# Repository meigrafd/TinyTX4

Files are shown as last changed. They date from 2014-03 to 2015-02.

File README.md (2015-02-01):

TinyTX4
=======

RFM12B based TinyTX Transmitter

Projekt Page: http://www.forum-raspberrypi.de/Thread-messen-steuern-regeln-batteriebetriebene-funk-sensoren

## Compiled Sketch size

#### with RFM12B lib:

Send_DHT22.ino --> 5.254 Bytes.  
Send_DHT22.ino & encrypt --> 6.896 Bytes.  
Send_DHT22_Watchdog.ino --> 5.512 Bytes.  
Send_DHT22_Watchdog.ino & encrypt --> 7.154 Bytes.  

Send_DS18B20.ino --> 7.342 Bytes.  
Send_DS18B20.ino & encrypt --> ... 768 bytes to big.  
Send_DS18B20_Watchdog.ino --> 7.590 Bytes.  
Send_DS18B20_Watchdog.ino & encrypt --> ... 1012 bytes to big.  

Send_ReedSwitch_Watchdog.ino --> 4.312 Bytes.  
Send_ReedSwitch_Watchdog.ino & encrypt --> 5.954 Bytes.  

#### with JeeLib:

Send_DHT22_Watchdog_JeeLib.ino --> 5.082 Bytes.  
Send_DHT22_Watchdog_JeeLib.ino & encrypt --> 6.746 Bytes.  

Send_DS18B20_Watchdog_JeeLib.ino --> 7.160 Bytes.  
Send_DS18B20_Watchdog_JeeLib.ino & encrypt --> ... 578 bytes to big.  

Send_ReedSwitch_Watchdog_JeeLib.ino --> 3.870 Bytes.  
Send_ReedSwitch_Watchdog_JeeLib.ino & encrypt --> 5.534 Bytes.  

Send_BMP085_Watchdog_JeeLib.ino --> 6.266 Bytes.  
Send_BMP085_Watchdog_JeeLib.ino & encrypt --> 7.894 Bytes.

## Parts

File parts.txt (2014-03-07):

Partlist

Exported from tinytx3.brd at 17.02.2014 13:12:31

EAGLE Version 6.4.0 Copyright (c) 1988-2013 CadSoft

Assembly variant: 

Part         Value          Package  Library        Position (mm)         Orientation

ANT                         1,6/0,8  wirepad        (20.86 6.25)          R0
BATANSCHLUSS                1X02     pinhead        (15.24 2.54)          R0
C1           100n           C0805    rcl            (27.48 6.35)          R180
C2           100n           C0805    rcl            (14.45 27.07)         MR90
C3                          C0805    rcl            (27.94 11.43)         R0
C4                          C0805    rcl            (31.75 8.89)          R0
IC1          ATTINY84       SOIC14   avr-5          (7.82 25.8)           MR0
JP1          No Booster     1X02     pinhead        (22.86 2.54)          R180
JP2                         1X03     pinhead        (39.37 34.29)         R0
JP3                         1X03     pinhead        (39.37 30.48)         R0
JP4                         1X03     pinhead        (39.37 26.67)         R0
JP5                         1X03     pinhead        (39.37 22.86)         R0
JP6                         1X03     pinhead        (39.37 19.05)         R0
JP7                         1X03     pinhead        (39.37 15.24)         R0
JP8                         1X03     pinhead        (39.37 11.43)         R0
JP9                         1X03     pinhead        (39.37 7.62)          R0
JP10                        1X02     pinhead        (40.64 3.81)          R0
L1           L1616FPS       L1616    L1616FSR       (29.21 17.78)         R0
PAD1                        1,6/0,9  wirepad        (13.97 36.83)         R0
PAD2                        1,6/0,9  wirepad        (16.51 36.83)         R0
PAD3                        1,6/0,9  wirepad        (19.05 36.83)         R0
PAD4                        1,6/0,9  wirepad        (21.59 36.83)         R0
PAD5                        1,6/0,9  wirepad        (24.13 36.83)         R0
PAD6                        1,6/0,9  wirepad        (26.67 36.83)         R0
PAD7                        1,6/0,9  wirepad        (29.21 36.83)         R0
PAD8                        1,6/0,9  wirepad        (31.75 36.83)         R0
PAD9                        1,6/0,9  wirepad        (13.97 34.29)         R0
PAD10                       1,6/0,9  wirepad        (16.51 34.29)         R0
PAD11                       1,6/0,9  wirepad        (19.05 34.29)         R0
PAD12                       1,6/0,9  wirepad        (21.59 34.29)         R0
PAD13                       1,6/0,9  wirepad        (24.13 34.29)         R0
PAD14                       1,6/0,9  wirepad        (26.67 34.29)         R0
PAD15                       1,6/0,9  wirepad        (29.21 34.29)         R0
PAD16                       1,6/0,9  wirepad        (31.75 34.29)         R0
R1           10k            R0805    rcl            (30.48 21.59)         MR270
SV1                         1X08     pinhead        (22.86 39.37)         R0
SV2                         ML6      con-harting-ml (25.4 25.4)           R0
U$1          RFM12B         RFM12B   JeeParts       (11.43 13.87)         R0
U$2          LTC3525        TSOT23-6 ltc3525        (29.21 13.97)         R270

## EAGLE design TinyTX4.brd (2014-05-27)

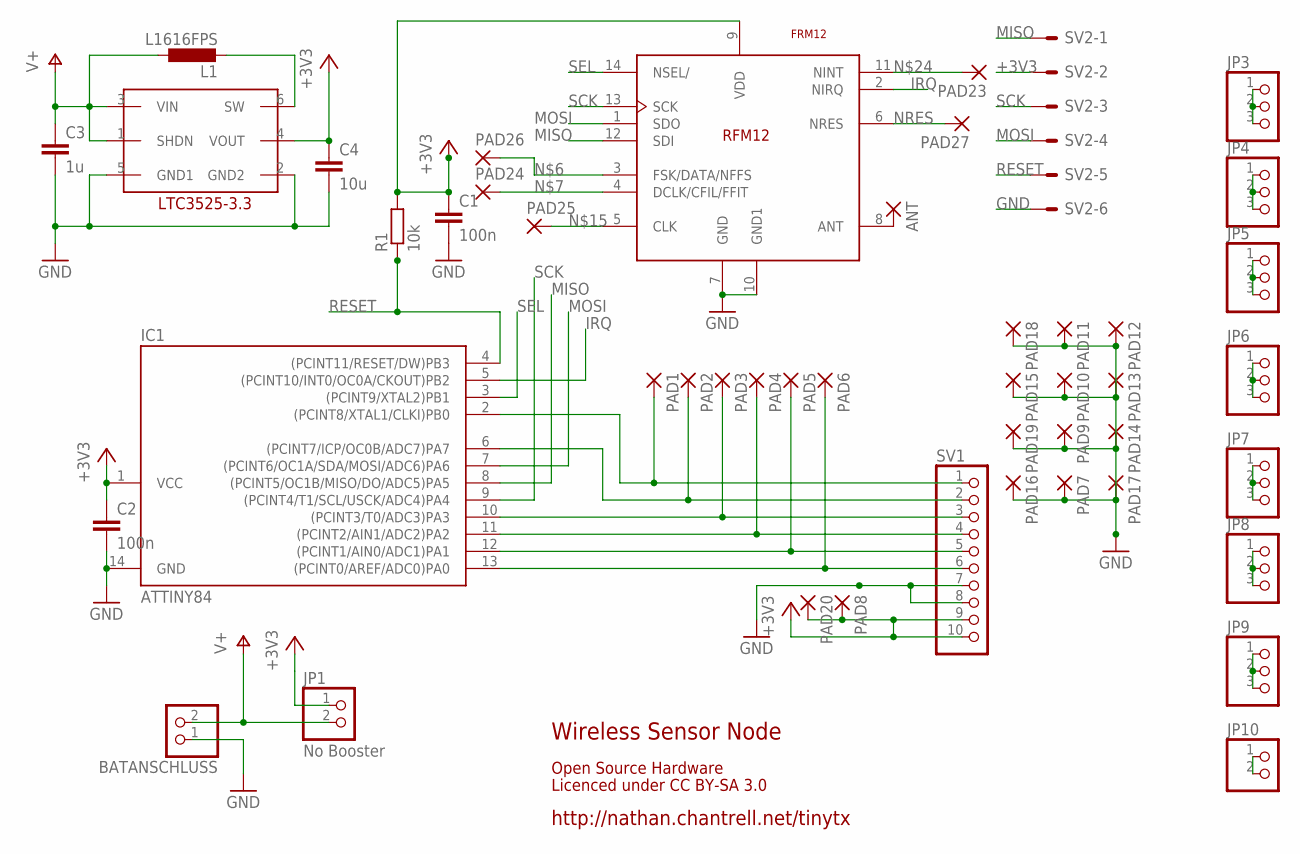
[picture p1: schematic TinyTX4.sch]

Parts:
ANT: 1,6/0,8
BATANSCHLUSS: PINHD-1X2; 1X02
C1, C2: 100n; C0805
C3: 1u; C0805
C4: 10u; C0805
IC1: ATTINY84; SOIC14
IC2: IC2; TSOT23-6
JP1: No Booster; 1X02
JP3, JP4, JP5, JP6, JP7, JP8, JP9: PINHD-1X3; 1X03
JP10: PINHD-1X2; 1X02
L1: L1616FPS; L1616
PAD1, PAD2, PAD3, PAD4, PAD5, PAD6, PAD7, PAD8, PAD9, PAD10, PAD11, PAD12, PAD13, PAD14, PAD15, PAD16, PAD17, PAD18, PAD19, PAD20, PAD23, PAD24, PAD25, PAD26, PAD27: 1,6/0,9
R1: 10k; R0805
SV1: PINHD-1X10; 1X10
SV2: ML6E; ML6
U$3: FRM12; RFM12

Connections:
+3V3: C1.1, C2.1, C4.1, IC1.1 (VCC), IC2.4 (VOUT), JP1.1, PAD8.1, PAD20.1, R1.2, SV1.9, SV1.10, SV2.2, U$3.9 (VDD)
ANT: ANT.1, U$3.8 (ANT)
GND: BATANSCHLUSS.1, C1.2, C2.2, C3.2, C4.2, IC1.14 (GND), IC2.2 (GND2), IC2.5 (GND1), PAD7.1, PAD9.1, PAD10.1, PAD11.1, PAD12.1, PAD13.1, PAD14.1, PAD15.1, PAD16.1, PAD17.1, PAD18.1, PAD19.1, SV1.7, SV1.8, SV2.6, U$3.7 (GND), U$3.10 (GND1)
IRQ: IC1.5 ((PCINT10/INT0/OC0A/CKOUT)PB2), U$3.2 (NIRQ)
MISO: IC1.8 ((PCINT5/OC1B/MISO/DO/ADC5)PA5), SV2.1, U$3.12 (SDI)
MOSI: IC1.7 ((PCINT6/OC1A/SDA/MOSI/ADC6)PA6), SV2.4, U$3.1 (SDO)
unnamed: PAD26.1, U$3.3 (FSK/DATA/NFFS)
unnamed: PAD24.1, U$3.4 (DCLK/CFIL/FFIT)
unnamed: IC1.6 ((PCINT7/ICP/OC0B/ADC7)PA7), PAD2.1, SV1.2
unnamed: IC1.13 ((PCINT0/AREF/ADC0)PA0), PAD6.1, SV1.6
unnamed: IC1.12 ((PCINT1/AIN0/ADC1)PA1), PAD5.1, SV1.5
unnamed: IC1.2 ((PCINT8/XTAL1/CLKI)PB0), PAD1.1, SV1.1
unnamed: IC2.6 (SW), L1.P$2 (2)
unnamed: IC1.11 ((PCINT2/AIN1/ADC2)PA2), PAD4.1, SV1.4
unnamed: IC1.10 ((PCINT3/T0/ADC3)PA3), PAD3.1, SV1.3
unnamed: PAD25.1, U$3.5 (CLK)
unnamed: JP3.1, JP3.2, JP3.3
unnamed: JP4.1, JP4.2, JP4.3
unnamed: JP5.1, JP5.2, JP5.3
unnamed: JP10.1, JP10.2
unnamed: JP6.1, JP6.2, JP6.3
unnamed: JP9.1, JP9.2, JP9.3
unnamed: JP7.1, JP7.2, JP7.3
unnamed: JP8.1, JP8.2, JP8.3
unnamed: PAD23.1, U$3.11 (NINT)
NRES: PAD27.1, U$3.6 (NRES)
RESET: IC1.4 ((PCINT11/RESET/DW)PB3), R1.1, SV2.5
SCK: IC1.9 ((PCINT4/T1/SCL/USCK/ADC4)PA4), SV2.3, U$3.13 (SCK)
SEL: IC1.3 ((PCINT9/XTAL2)PB1), U$3.14 (NSEL/)
V+: BATANSCHLUSS.2, C3.1, IC2.1 (SHDN), IC2.3 (VIN), JP1.2, L1.P$1 (1)

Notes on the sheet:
http://nathan.chantrell.net/tinytx
Wireless Sensor Node
Licenced under CC BY-SA 3.0
Open Source Hardware

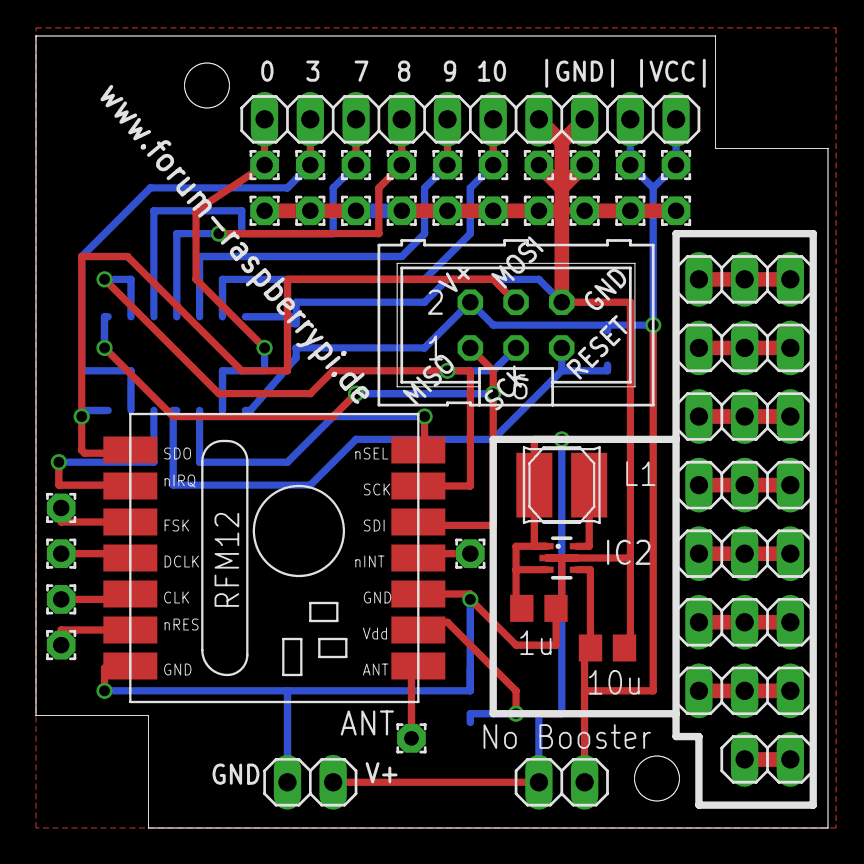
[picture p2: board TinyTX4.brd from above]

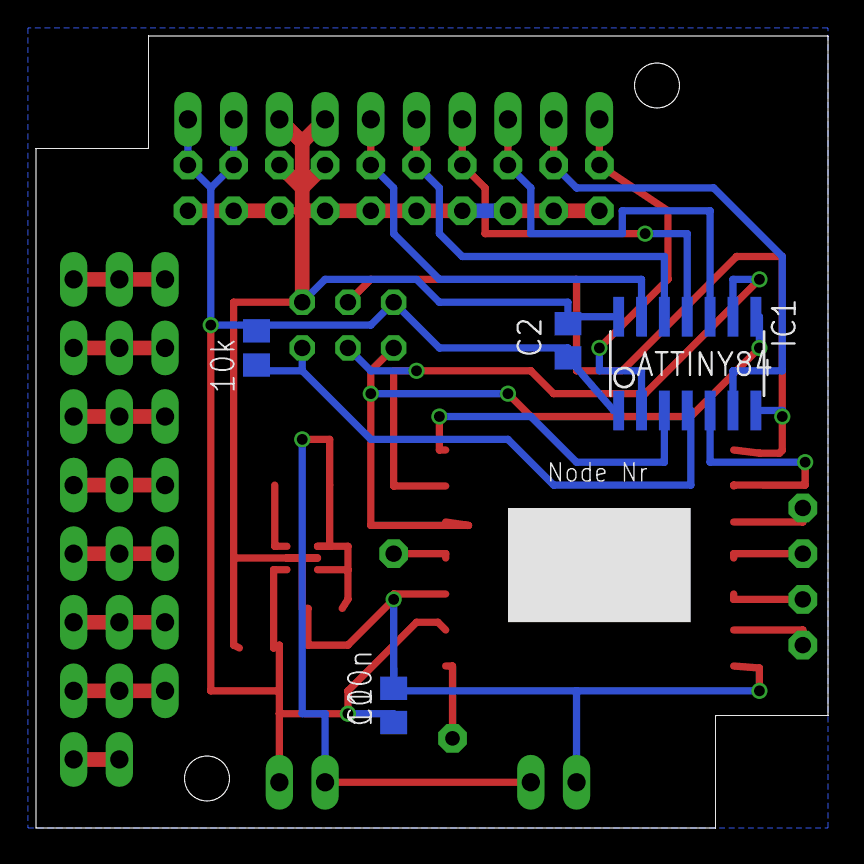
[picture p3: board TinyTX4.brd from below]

Board: 2 copper layers, 44.0 x 44.0 mm, 47 parts (4 on the bottom side), 30 nets.

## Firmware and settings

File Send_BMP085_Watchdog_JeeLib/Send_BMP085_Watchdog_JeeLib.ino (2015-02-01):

//----------------------------------------------------------------------------------------------------------------------
// RFM12B Sender for BMP085 Wireless Air Pressure/Temperature Sensor with Watchdog (saves much more Power!)
//
// Using the BMP085 sensor connected via I2C
// I2C can be connected with SDA to D8 and SCL to D7 or SDA to D10 and SCL to D9
//
//
//  NOTE: SCL and SDA needs pull-up resistors for each I2C bus.
//  2.2kOhm...10kOhm, typ. 4.7kOhm
//----------------------------------------------------------------------------------------------------------------------
// modified by meigrafd @ 01.02.2015
//----------------------------------------------------------------------------------------------------------------------
#include <JeeLib.h> // https://github.com/jcw/jeelib
#include <PortsBMP085.h> // Part of JeeLib
#include <avr/sleep.h>

// Power-Save-Stuff.
// http://www.surprisingedge.com/low-power-atmegatiny-with-watchdog-timer/
// https://www.sparkfun.com/tutorials/309
// http://jeelabs.org/tag/lowpower/
volatile int watchdog_counter;
// Watchdog Interrupt Service / is executed when  watchdog timed out
ISR(WDT_vect) { watchdog_counter++; }

// 0=16ms, 1=32ms, 2=64ms, 3=128ms, 4=250ms, 5=500ms
// 6=1sec, 7=2sec, 8=4sec, 9=8sec
// From: http://interface.khm.de/index.php/lab/experiments/sleep_watchdog_battery/
int watchdog_wakeup = 9;  // Wake up after 8 sec
//------------------------------------------------------------------------------
// You will need to initialize the radio by telling it what ID it has and what network it's on
// The NodeID takes values from 1-127, 0 is reserved for sending broadcast messages (send to all nodes)
// The Network ID takes values from 0-255
// By default the SPI-SS line used is D10 on Atmega328. You can change it by calling .SetCS(pin) where pin can be {8,9,10}
#define NODEID         20   // network ID used for this unit
#define NETWORKID     210   // the network ID we are on
#define GATEWAYID      22   // the node ID we're sending to
#define FREQ   RF12_433MHZ  // Frequency of RFM12B module

#define ACK_TIME     2000   // # of ms to wait for an ack
#define requestACK   false   // request ACK? (true/false)
#define SENDDELAY  300000   // wait this many ms between sending packets. 300000ms / 1000 / 8 = 37,5 * 8sec = 5Min.
//------------------------------------------------------------------------------
// PIN-Konfiguration 
//------------------------------------------------------------------------------
// SENSOR pins
#define BMP085_POWER 9   // BMP085 Power pin is connected on D9
PortI2C i2c (2);         // BMP085 SDA to D8 and SCL to D7
//PortI2C i2c (1);      // BMP085 SDA to D10 and SCL to D9
// LED pin
#define LEDpin 0         // D8, PA2 (ATtiny pin 11) - set to 0 to disable LED
//------------------------------------------------------------------------------
/*
                     +-\/-+
               VCC  1|    |14  GND
          (D0) PB0  2|    |13  AREF (D10)
          (D1) PB1  3|    |12  PA1 (D9)
       (PB3) RESET  4|    |11  PA2 (D8)
INT0  PWM (D2) PB2  5|    |10  PA3 (D7)
      PWM (D3) PA7  6|    |9   PA4 (D6) SCK
SDA   PWM (D4) PA6  7|    |8   PA5 (D5) PWM
                     +----+
*/

//Modes:
// MODE_ULTRA_LOW_POWER    0 //oversampling=0, internalsamples=1, maxconvtimepressure=4.5ms, avgcurrent=3uA, RMSnoise_hPA=0.06, RMSnoise_m=0.5
// MODE_STANDARD           1 //oversampling=1, internalsamples=2, maxconvtimepressure=7.5ms, avgcurrent=5uA, RMSnoise_hPA=0.05, RMSnoise_m=0.4
// MODE_HIGHRES            2 //oversampling=2, internalsamples=4, maxconvtimepressure=13.5ms, avgcurrent=7uA, RMSnoise_hPA=0.04, RMSnoise_m=0.3
// MODE_ULTRA_HIGHRES      3 //oversampling=3, internalsamples=8, maxconvtimepressure=25.5ms, avgcurrent=12uA, RMSnoise_hPA=0.03, RMSnoise_m=0.25
BMP085 psensor (i2c, 3); // ultra high resolution

//encryption is OPTIONAL
//to enable encryption you will need to:
// - provide a 16-byte encryption KEY (same on all nodes that talk encrypted)
// - to call .Encrypt(KEY) to start encrypting
// - to stop encrypting call .Encrypt(NULL)
//#define KEY   "ABCDABCDABCDABCD"

// Temperatur-String zum Versand
char msg[26];

int16_t temp;	// Temperature reading
int32_t pres;	// Pressure reading

// 7,5 * 8sec = 1 Min. 37,5 * 8sec = 5Min.
int watchdog_limit = SENDDELAY / 1000 / 8;

//########################################################################################################################

static void activityLed (byte state, byte time = 0) {
  if (LEDpin) {
    pinMode(LEDpin, OUTPUT);
    if (time == 0) {
      digitalWrite(LEDpin, state);
    } else {
      digitalWrite(LEDpin, state);
      delay(time);
      digitalWrite(LEDpin, !state);
    }
  }
}

// blink led
static void blink (byte pin, byte n = 3) {
  if (LEDpin) {
    pinMode(pin, OUTPUT);
    for (byte i = 0; i < 2 * n; ++i) {
      delay(100);
      digitalWrite(pin, !digitalRead(pin));
    }
  }
}

//--------------------------------------------------------------------------------------------------
// Read current supply voltage
//--------------------------------------------------------------------------------------------------
long readVcc() {
  // Read 1.1V reference against AVcc
  // set the reference to Vcc and the measurement to the internal 1.1V reference
  #if defined(__AVR_ATmega32U4__) || defined(__AVR_ATmega1280__) || defined(__AVR_ATmega2560__)
      ADMUX = _BV(REFS0) | _BV(MUX4) | _BV(MUX3) | _BV(MUX2) | _BV(MUX1);
  #elif defined (__AVR_ATtiny24__) || defined(__AVR_ATtiny44__) || defined(__AVR_ATtiny84__)
      ADMUX = _BV(MUX5) | _BV(MUX0);
  #elif defined (__AVR_ATtiny25__) || defined(__AVR_ATtiny45__) || defined(__AVR_ATtiny85__)
      ADMUX = _BV(MUX3) | _BV(MUX2);
  #else
      ADMUX = _BV(REFS0) | _BV(MUX3) | _BV(MUX2) | _BV(MUX1);
  #endif
  delay(2); // Wait for Vref to settle
  ADCSRA |= _BV(ADSC); // Start conversion
  while (bit_is_set(ADCSRA,ADSC)); // measuring
  uint8_t low  = ADCL; // must read ADCL first - it then locks ADCH
  uint8_t high = ADCH; // unlocks both
  long result = (high<<8) | low;
  //result = 1125300L / result; // Back-Calculate Vcc (in mV); 1125300 = 1.1*1023*1000
  result = 1126400L / result; // Back-calculate Vcc in mV
  return result;
}

//--------------------------------------------------------------------------------------------------
// Power Save Functions
//--------------------------------------------------------------------------------------------------

// Enable / Disable ADC, saves ~230uA
void enableADC(bool b) {
  if (b == true){
    bitClear(PRR, PRADC); // power up the ADC
    ADCSRA |= bit(ADEN);  // enable the ADC
    delay(10);
  } else {
    ADCSRA &= ~ bit(ADEN); // disable the ADC
    bitSet(PRR, PRADC);    // power down the ADC
  }
}

// send ATtiny into Power Save Mode
void goToSleep() {
  // SLEEP_MODE_IDLE -the least power savings
  // SLEEP_MODE_ADC
  // SLEEP_MODE_PWR_SAVE
  // SLEEP_MODE_STANDBY
  // SLEEP_MODE_PWR_DOWN -the most power savings
  set_sleep_mode(SLEEP_MODE_PWR_DOWN); // Set sleep mode.
  sleep_enable(); // Enable sleep mode.
  sleep_mode(); // Enter sleep mode.

  // After waking from watchdog interrupt the code continues to execute from this point.

  sleep_disable(); // Disable sleep mode after waking.
  // Re-enable the peripherals.
  //power_all_enable();
}

// 0=16ms, 1=32ms, 2=64ms, 3=128ms, 4=250ms, 5=500ms
// 6=1sec, 7=2sec, 8=4sec, 9=8sec
// From: http://interface.khm.de/index.php/lab/experiments/sleep_watchdog_battery/
void setup_watchdog(int timerPrescaler) {
  if (timerPrescaler > 9 ) timerPrescaler = 9; //Correct incoming amount if need be
  byte bb = timerPrescaler & 7; 
  if (timerPrescaler > 7) bb |= (1<<5); //Set the special 5th bit if necessary
  //This order of commands is important and cannot be combined
  MCUSR &= ~(1<<WDRF); //Clear the watchdog reset
  WDTCSR |= (1<<WDCE) | (1<<WDE); //Set WD_change enable, set WD enable
  WDTCSR = bb; //Set new watchdog timeout value
  WDTCSR |= _BV(WDIE); //Set the interrupt enable, this will keep unit from resetting after each int
}

//########################################################################################################################

void setup() {
  pinMode(BMP085_POWER, OUTPUT); // set power pin for BMP085 to output
  digitalWrite(BMP085_POWER, HIGH); // turn BMP085 sensor on
  Sleepy::loseSomeTime(50); // Allow 50ms for the sensor to be ready
  psensor.getCalibData();
  
  rf12_initialize(NODEID, FREQ, NETWORKID);
  #ifdef KEY
    rf12_encrypt((byte*)KEY);      //comment this out to disable encryption
  #endif
  // configure RFM12B
  rf12_control(0xC040);   // Adjust low battery voltage to 2.2V
  rf12_sleep(0); //sleep right away to save power

  // 0=16ms, 1=32ms, 2=64ms, 3=128ms, 4=250ms, 5=500ms
  // 6=1sec, 7=2sec, 8=4sec, 9=8sec
  // From: http://interface.khm.de/index.php/lab/experiments/sleep_watchdog_battery/
  setup_watchdog(watchdog_wakeup);      // Wake up after 8 sec
  watchdog_counter = 500; // set to have an initial transmition when starting the sender.

  PRR = bit(PRTIM1); // only keep timer 0 going
  enableADC(false);           // power down/disable the ADC
  analogReference(INTERNAL);   // Set the aref to the internal 1.1V reference

  if (LEDpin) {
    activityLed(1, 1000); // LED on for 1000ms (1sec)
  }
}

void loop() {
  goToSleep(); // goes to sleep for about 8 seconds and continues to execute code when it wakes up

  if (watchdog_counter >= watchdog_limit) {
    watchdog_counter = 1;

    enableADC(true); // power up/enable the ADC

    pinMode(BMP085_POWER, OUTPUT); // set power pin for BMP085 to output
    digitalWrite(BMP085_POWER, HIGH); // turn BMP085 sensor on
    
    // Get raw temperature reading
    psensor.startMeas(BMP085::TEMP);
    Sleepy::loseSomeTime(16); // Allow 16ms for the sensor to be ready
    int32_t traw = psensor.getResult(BMP085::TEMP);
  
    // Get raw pressure reading
    psensor.startMeas(BMP085::PRES);
    Sleepy::loseSomeTime(32); // Allow 32ms for the sensor to get data
    int32_t praw = psensor.getResult(BMP085::PRES);
   
    // Calculate actual temperature and pressure
    int32_t press;
    psensor.calculate(temp, press);
    pres = (press * 0.01);
  
    // Get supply voltage
    int supplyV = readVcc();
  
    // msg-Variable mit Daten zum Versand fuellen, die spaeter an das WebScript uebergeben werden
    strcpy(msg,"v=");
    itoa(supplyV,&msg[strlen(msg)],10);
    strcat(msg,"&t=");
    itoa(temp,&msg[strlen(msg)],10);
    strcat(msg,"&p=");
    itoa(pres,&msg[strlen(msg)],10);
  
    rf12_sleep(-1);  // Wake up RF module
    while (!rf12_canSend())
    rf12_sendStart(GATEWAYID, (uint8_t *)msg, strlen(msg), requestACK);
    rf12_sendWait(2);    //wait for RF to finish sending (2=standby mode, 3=power down)
    rf12_sleep(0);
  
    if (LEDpin) {
      blink(LEDpin, 2); // blink LED
    }
  
    digitalWrite(BMP085_POWER, LOW); // turn Sensor off to save power
    pinMode(BMP085_POWER, INPUT); // set power pin for Sensor to input before sleeping, saves power
    enableADC(false); // power down/disable the ADC
  }
}

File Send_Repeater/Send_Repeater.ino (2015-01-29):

// RFM12B Repeater
//
// Relays from one Network Group to another maintaining the Node ID
//
// Avoid using any code with interrupts (e.g powersaving watchdogs)
// as it seems to cause resets and the setup code to execute again
// Power Saving doesn't really make sense for a Relay as it needs to be listening all the time
// and I would expect it to be running from a mains PSU or similar.
//
// modified by meigrafd @ 06.01.2015
//------------------------------------------------------------------------------
#include <RFM12B.h>

//------------------------------------------------------------------------------

// Enable SoftwareSerial for debugging?
#define DEBUG 1
#define SERIAL_BAUD     9600

//------------------------------------------------------------------------------
// You will need to initialize the radio by telling it what ID it has and what network it's on
// The NodeID takes values from 1-127, 0 is reserved for sending broadcast messages (send to all nodes)
// The Network ID takes values from 0-255

// Receive settings - where Senders send to
#define NODEID         22   // network ID used for this unit
#define NETWORKID     210   // the network ID we are on
#define FREQ  RF12_433MHZ   // Frequency of RFM12B module
#define ACK_TIME     2000   // # of ms to wait for an ack
#define requestACK   false   // request ACK? (true/false)

// Transmit settings - where Repeater sends to PI
#define T_NODEID          1   // network ID used for this unit
#define T_NETWORKID     220   // the network ID we are on
#define T_GATEWAYID      22   // the node ID we're sending to
#define T_FREQ  RF12_433MHZ   // Frequency of RFM12B module
#define T_ACK_TIME     2000   // # of ms to wait for an ack
#define T_requestACK   false   // request ACK? (true/false)

// UART pins - only for DEBUG
#define rxPin 7 // D7, PA3
#define txPin 3 // D3, PA7. pin der an RXD vom PI geht.

// LED pin
#define LEDpin 8 // D8, PA2 - set to 0 to disable LED
//------------------------------------------------------------------------------
/*
                     +-\/-+
               VCC  1|    |14  GND
          (D0) PB0  2|    |13  AREF (D10)
          (D1) PB1  3|    |12  PA1 (D9)
             RESET  4|    |11  PA2 (D8)
INT0  PWM (D2) PB2  5|    |10  PA3 (D7)
      PWM (D3) PA7  6|    |9   PA4 (D6)
      PWM (D4) PA6  7|    |8   PA5 (D5) PWM
                     +----+
*/

//encryption is OPTIONAL
//to enable encryption you will need to:
// - provide a 16-byte encryption KEY (same on all nodes that talk encrypted)
// - to call .Encrypt(KEY) to start encrypting
// - to stop encrypting call .Encrypt(NULL)
//#define KEY   "a4gBM69UZ03lQyK4"

// Need an instance of the Radio Module
RFM12B radio;

#ifdef DEBUG
  #include <SoftwareSerial.h>
  // Initialise UART
  SoftwareSerial mySerial(rxPin, txPin);
#endif


String inputString;

//##############################################################################

static void activityLED (byte state, byte time = 0) {
  if (LEDpin) {
    pinMode(LEDpin, OUTPUT);
    if (time == 0) {
      digitalWrite(LEDpin, state);
    } else {
      digitalWrite(LEDpin, state);
      delay(time);
      digitalWrite(LEDpin, !state);
    }
  }
}

// blink led
static void blink (byte pin, byte n = 3) {
  if (LEDpin) {
    pinMode(pin, OUTPUT);
    for (byte i = 0; i < 2 * n; ++i) {
      delay(100);
      digitalWrite(pin, !digitalRead(pin));
    }
  }
}

void enableADC(bool b) {
  if (b == true){
    bitClear(PRR, PRADC); // power up the ADC
    ADCSRA |= bit(ADEN); // enable the ADC
    delay(10);
  } else {
    //ADCSRA &= ~(1<<ADEN); // Disable ADC, saves ~230uA
    ADCSRA &= ~ bit(ADEN); // disable the ADC
    bitSet(PRR, PRADC); // power down the ADC
  }
}

//--------------------------------------------------------------------------------------------------
// Read current supply voltage (in mV)
//--------------------------------------------------------------------------------------------------
long readVcc() {
  enableADC(true);
  // Read 1.1V reference against AVcc
  // set the reference to Vcc and the measurement to the internal 1.1V reference
  #if defined(__AVR_ATmega32U4__) || defined(__AVR_ATmega1280__) || defined(__AVR_ATmega2560__)
      ADMUX = _BV(REFS0) | _BV(MUX4) | _BV(MUX3) | _BV(MUX2) | _BV(MUX1);
  #elif defined (__AVR_ATtiny24__) || defined(__AVR_ATtiny44__) || defined(__AVR_ATtiny84__)
      ADMUX = _BV(MUX5) | _BV(MUX0);
  #elif defined (__AVR_ATtiny25__) || defined(__AVR_ATtiny45__) || defined(__AVR_ATtiny85__)
      ADMUX = _BV(MUX3) | _BV(MUX2);
  #else
      ADMUX = _BV(REFS0) | _BV(MUX3) | _BV(MUX2) | _BV(MUX1);
  #endif
  delay(2); // Wait for Vref to settle
  ADCSRA |= _BV(ADSC); // Start conversion
  while (bit_is_set(ADCSRA,ADSC)); // measuring
  uint8_t low  = ADCL; // must read ADCL first - it then locks ADCH
  uint8_t high = ADCH; // unlocks both
  long result = (high<<8) | low;
  //result = 1125300L / result; // Back-Calculate Vcc (in mV); 1125300 = 1.1*1023*1000
  result = 1126400L / result; // Back-calculate Vcc in mV
  enableADC(false);
  return result;
}

//--------------------------------------------------------------------------------------------------

// Initialise the RFM12B for receiving
void setupReceive() {
  radio.Initialize(NODEID, FREQ, NETWORKID);
  #ifdef KEY
    radio.Encrypt((byte*)KEY); //comment this out to disable encryption
  #endif
}

// Initialise the RFM12B for relaying
void setupTransmit() {
  radio.Initialize(T_NODEID, T_FREQ, T_NETWORKID);
  #ifdef KEY
    radio.Encrypt((byte*)KEY); //comment this out to disable encryption
  #endif
}

// init Setup
void setup() {
  #ifdef DEBUG
    pinMode(rxPin, INPUT);
    pinMode(txPin, OUTPUT);
    mySerial.begin(SERIAL_BAUD);
  #endif
  setupReceive();
  radio.Control(0xC040); // Adjust low battery voltage to 2.2V

  enableADC(false); // power down/disable the ADC
  //ACSR = (1<<ACD); // Disable the analog comparator
  //DIDR0 = 0x3F; // Disable digital input buffers on all ADC0-ADC5 pins.
  //ADCSRA &= ~ bit(ADEN); bitSet(PRR, PRADC); // Disable the ADC to save power
  PRR = bit(PRTIM1); // only keep timer 0 going
  analogReference(INTERNAL);   // Set the aref to the internal 1.1V reference
  if (LEDpin) {
    activityLED(1,1000); // LED on
  }
}
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

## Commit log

2014-03-07 Public Build
    [TinyTX4.brd, TinyTX4.sch]
2014-05-27 Layoutkorrektur
    Gehäuse für LT3525 auf SC70 geändert
    [TinyTX4.brd]
2014-05-27 Layoutkorrektur - retry
    Gehäuse für LT3525 auf SC70 geändert. (2. Versuch)
    [TinyTX4.brd, TinyTX4.sch]
2014-05-27 Update TinyTX4.brd
    Fix for LTC3525 Package Size from TSOT23 to SC70
    [TinyTX4.brd]
2014-05-27 Update TinyTX4.sch
    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
    [TinyTX4.sch]
